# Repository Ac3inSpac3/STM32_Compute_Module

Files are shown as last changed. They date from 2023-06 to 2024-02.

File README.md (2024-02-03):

# Custom STM32 Compute Module

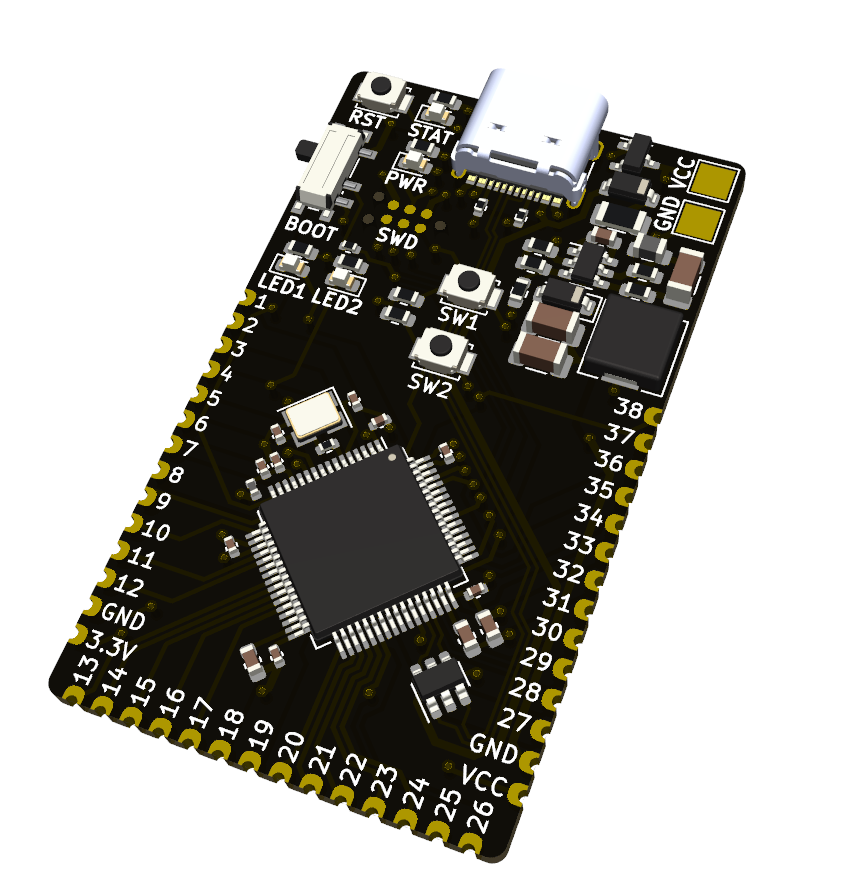
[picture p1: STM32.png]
Module Image


## Introduction

In order to wrap my head around using KiCAD I decided to design an STM32 compute module. The goal of this exercise was to familiarise myself with the program enough so that I was comfortable designing PCBs and getting them manufactured for Uni and personal projects. Due to the high cost of manufacturing this board and the possibility of it not working it was never manufactured/tested and was purely a way for me to learn how to use KiCAD.

## Features

- STM32F4 Microcontroller
- Full breakout of GPIO pins
- Voltage Regulator with fuse
- USBC
- SWD tag connector

## Module Overview

In theory this board is capable of being the heart of many different projects as a replacement for the slow Arduino boards.

## Images

### PCB

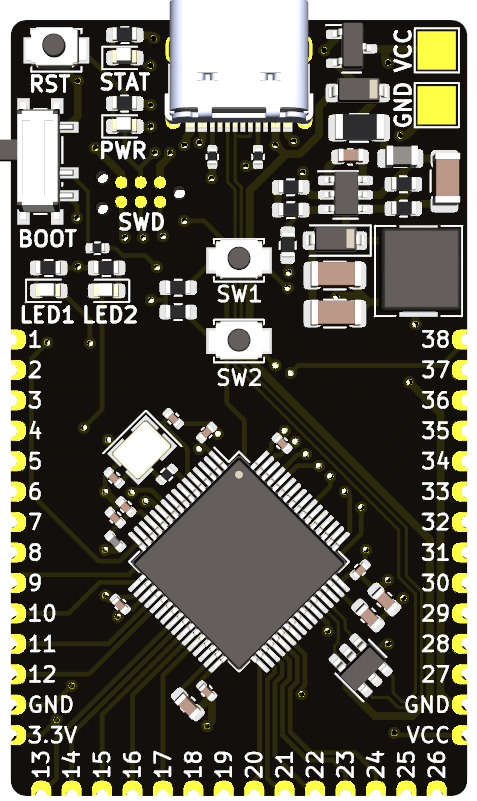
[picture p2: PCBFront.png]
Module Front


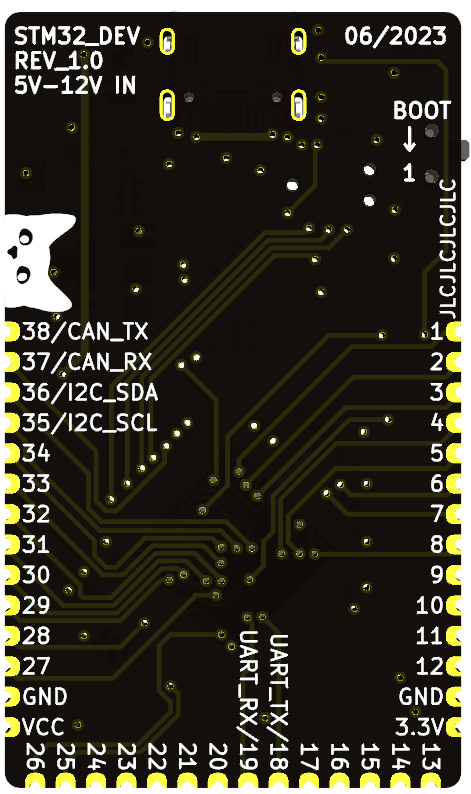
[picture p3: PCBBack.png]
Module Back


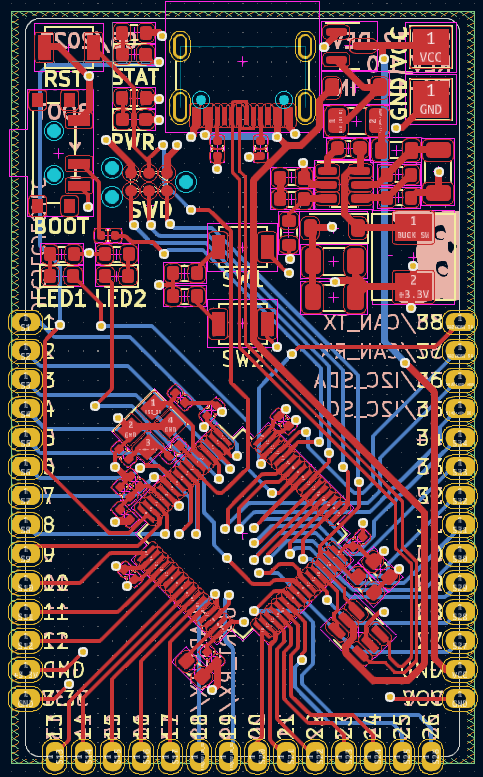
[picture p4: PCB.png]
PCB


### Schematic

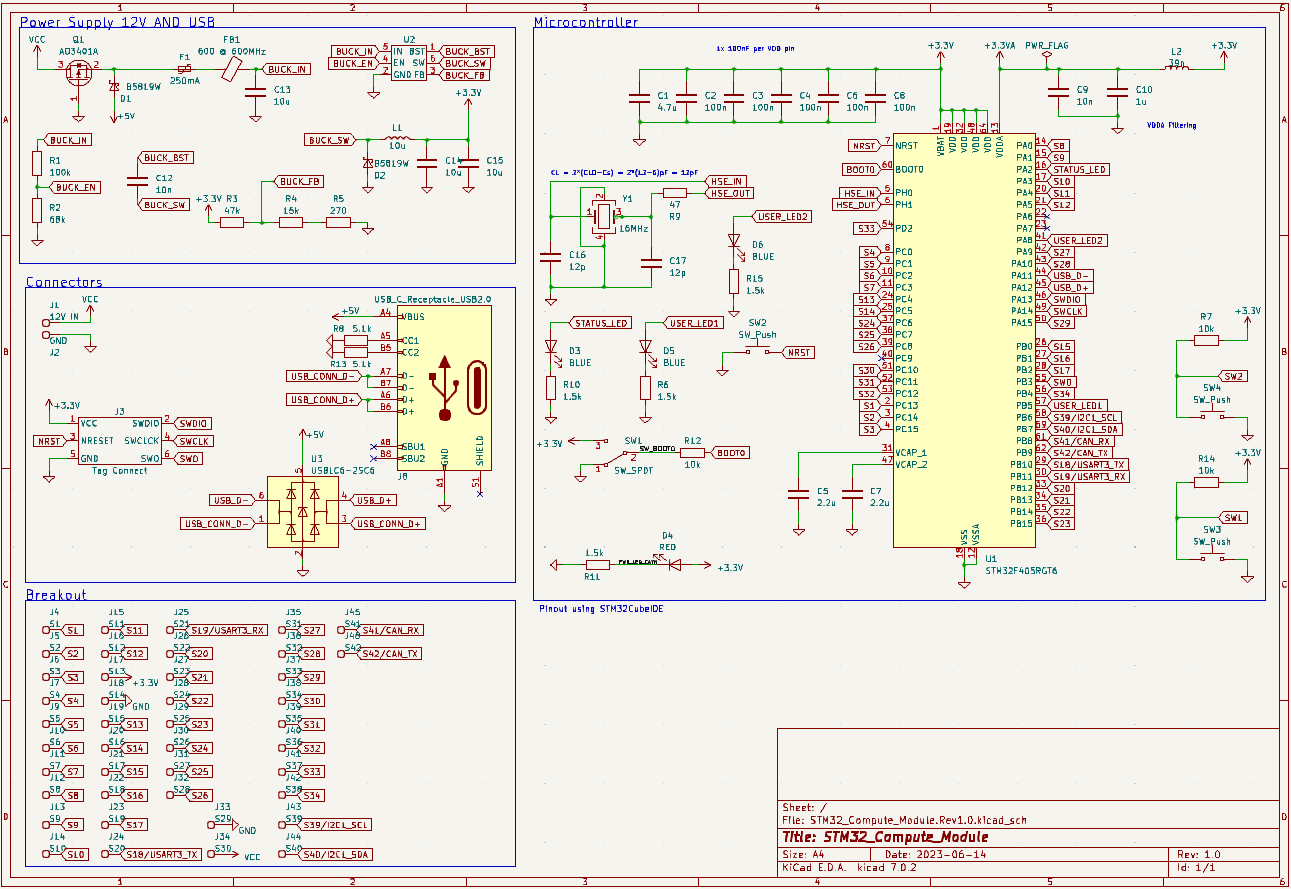
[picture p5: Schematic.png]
STM32 Schematic


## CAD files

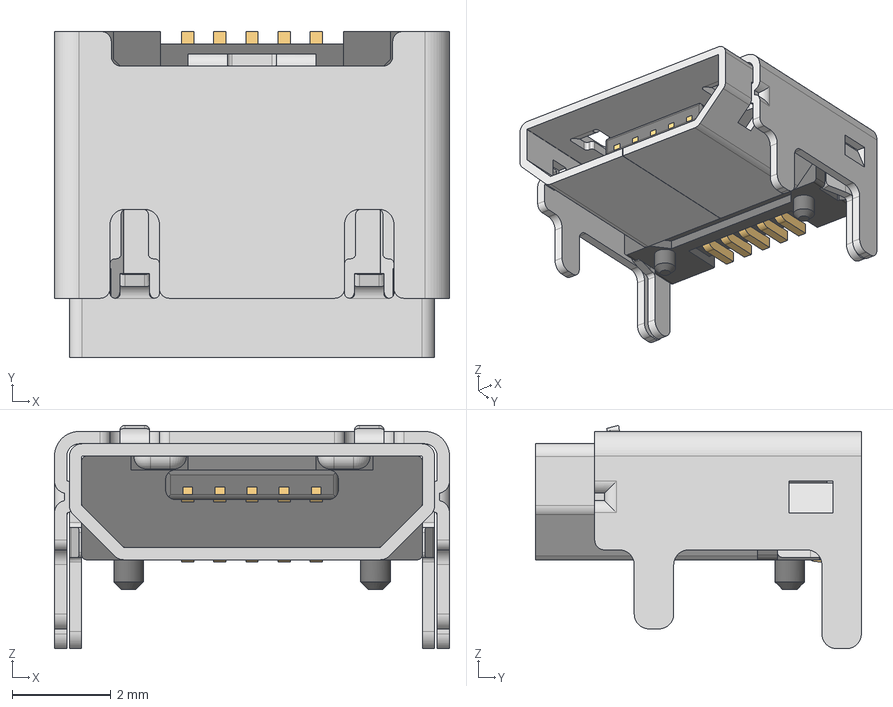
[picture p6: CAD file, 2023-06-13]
KiCAD/629105150521 (rev1).stp
8.00 x 6.60 x 4.52 mm
629105150521_Housing
629105150521_Pin1 x 4
629105150521_Pin2
629105150521_Shielding2
629105150521_Shielding

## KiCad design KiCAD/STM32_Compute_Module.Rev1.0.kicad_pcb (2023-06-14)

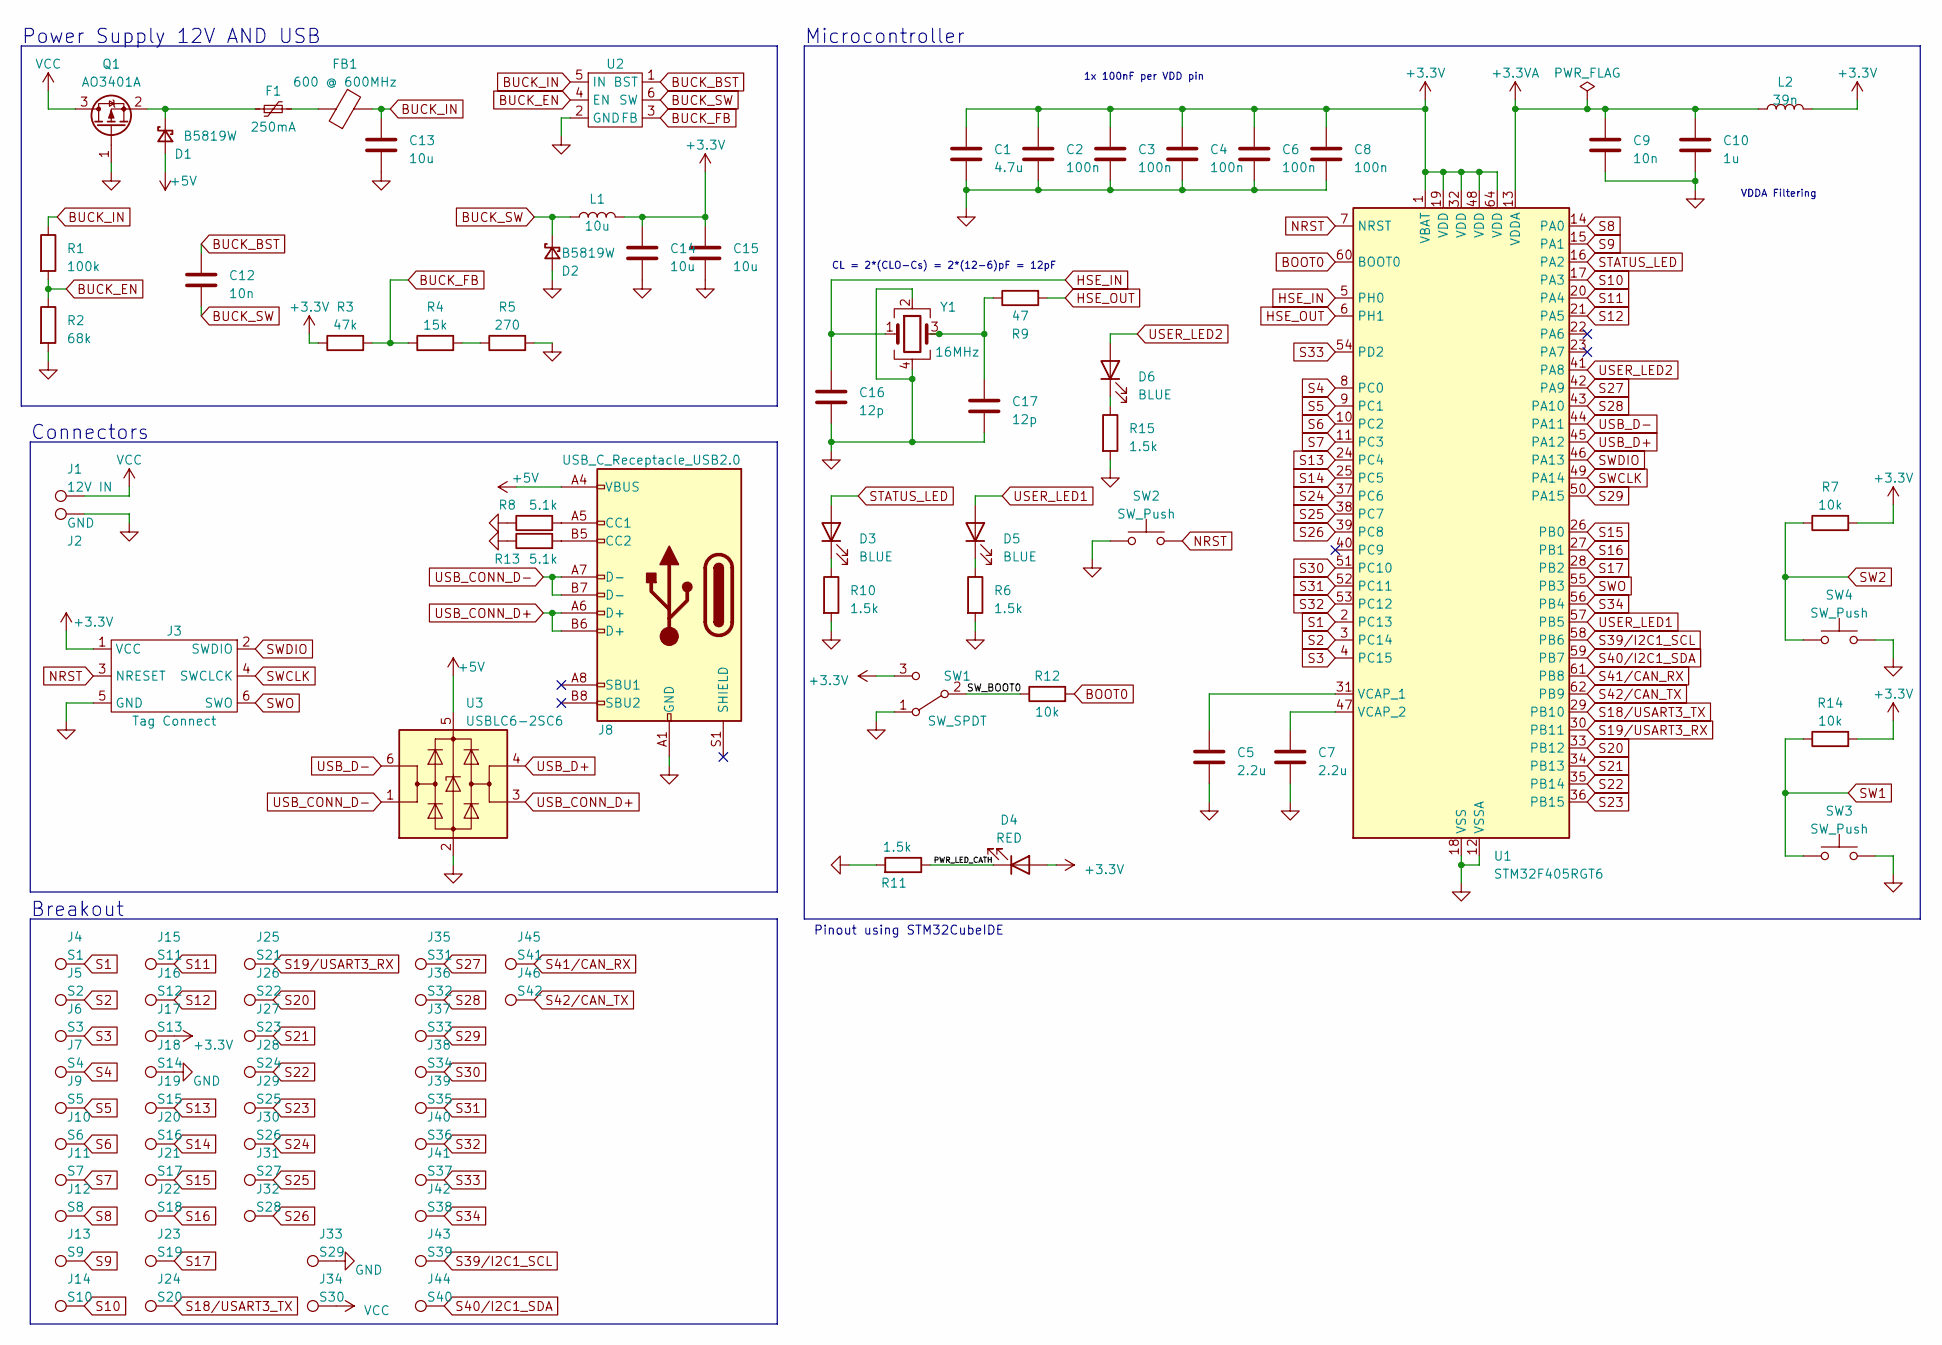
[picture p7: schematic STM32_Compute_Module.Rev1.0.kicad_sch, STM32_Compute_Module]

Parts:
C1: 4.7u; C_0603_1608Metric
C2, C3, C4, C6, C8: 100n; C_0402_1005Metric
C5, C7: 2.2u; C_0603_1608Metric
C9: 10n; C_0402_1005Metric
C10: 1u; C_0402_1005Metric
C12: 10n; C_0603_1608Metric
C13, C14, C15: 10u; C_1206_3216Metric
C16, C17: 12p; C_0402_1005Metric
D1, D2: B5819W; D_SOD-123
D3, D5, D6: BLUE; LED_0603_1608Metric
D4: RED; LED_0603_1608Metric
F1: 250mA; Fuse_1206_3216Metric
FB1: 600 @ 600MHz; L_0805_2012Metric
J1: 12V IN; TestPoint_Pad_2.5x2.5mm
J2: GND; TestPoint_Pad_2.5x2.5mm
J3: Tag Connect
J4: S1; Cas Pad
J5: S2; Cas Pad
J6: S3; Cas Pad
J7: S4; Cas Pad
J8: USB_C_Receptacle_USB2.0; USB_C_Receptacle_G-Switch_GT-USB-7010ASV
J9: S5; Cas Pad
J10: S6; Cas Pad
J11: S7; Cas Pad
J12: S8; Cas Pad
J13: S9; Cas Pad
J14: S10; Cas Pad
J15: S11; Cas Pad
J16: S12; Cas Pad
J17: S13; Cas Pad
J18: S14; Cas Pad
J19: S15; Cas Pad
J20: S16; Cas Pad
J21: S17; Cas Pad
J22: S18; Cas Pad
J23: S19; Cas Pad
J24: S20; Cas Pad
J25: S21; Cas Pad
J26: S22; Cas Pad
J27: S23; Cas Pad
J28: S24; Cas Pad
J29: S25; Cas Pad
J30: S26; Cas Pad
J31: S27; Cas Pad
J32: S28; Cas Pad
J33: S29; Cas Pad
J34: S30; Cas Pad
J35: S31; Cas Pad
J36: S32; Cas Pad
J37: S33; Cas Pad
J38: S34; Cas Pad
J39: S35; Cas Pad
J40: S36; Cas Pad
J41: S37; Cas Pad
J42: S38; Cas Pad
J43: S39; Cas Pad
J44: S40; Cas Pad
J45: S41; Cas Pad
J46: S42; Cas Pad
L1: 10u; L_Sunlord_MWSA0518S
L2: 39n; L_0402_1005Metric
Q1: AO3401A; SOT-23
R1: 100k; R_0603_1608Metric
R2: 68k; R_0603_1608Metric
R3: 47k; R_0603_1608Metric
R4: 15k; R_0603_1608Metric
R5: 270; R_0603_1608Metric
R6, R10, R11, R15: 1.5k; R_0603_1608Metric
R7, R14: 10k; R_0603_1608Metric
R8, R13: 5.1k; R_0402_1005Metric
R9: 47; R_0402_1005Metric
R12: 10k; R_0402_1005Metric
SW1: SW_SPDT; SW_SPDT_PCM12
SW2, SW3, SW4: SW_Push; SW_SPST_B3U-1000P
U1: STM32F405RGT6; LQFP-64_10x10mm_P0.5mm
U2: TSOT-23-6
U3: USBLC6-2SC6; SOT-23-6
Y1: 16MHz; Crystal_SMD_3225-4Pin_3.2x2.5mm

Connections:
+3.3V: C1.1, C2.1, C3.1, C4.1, C6.1, C8.1, C14.1, C15.1, D4.2 (A), J3.1 (VCC), J17.1, L1.2, L2.2, R3.1, R7.2, R14.2, SW1.3 (C), U1.1 (VBAT), U1.19 (VDD), U1.32 (VDD), U1.48 (VDD), U1.64 (VDD)
+3.3VA: C9.1, C10.1, L2.1, U1.13 (VDDA)
+5V: D1.2 (A), J8.A4 (VBUS), J8.A9 (VBUS), J8.B4 (VBUS), J8.B9 (VBUS), U3.5 (VBUS)
/PWR_LED_CATH: D4.1 (K), R11.1
/SW_BOOT0: R12.1, SW1.2 (B)
BOOT0: R12.2, U1.60 (BOOT0)
BUCK_BST: C12.1, U2.1 (BST)
BUCK_EN: R1.2, R2.1, U2.4 (EN)
BUCK_FB: R3.2, R4.1, U2.3 (FB)
BUCK_IN: C13.1, FB1.2, R1.1, U2.5 (IN)
BUCK_SW: C12.2, D2.1 (K), L1.1, U2.6 (SW)
GND: C1.2, C2.2, C3.2, C4.2, C5.2, C6.2, C7.2, C8.2, C9.2, C10.2, C13.2, C14.2, C15.2, C16.2, C17.2, D2.2 (A), J2.1, J3.5 (GND), J8.A1 (GND), J8.A12 (GND), J8.B1 (GND), J8.B12 (GND), J18.1, J33.1, Q1.1 (G), R2.2, R5.2, R6.2, R8.1, R10.2, R11.2, R13.1, R15.2, SW1.1 (A), SW2.1, SW3.1, SW4.1, U1.12 (VSSA), U1.18 (VSS), U1.63 (VSS), U2.2 (GND), U3.2 (GND), Y1.2, Y1.4
HSE_IN: C16.1, U1.5 (PH0), Y1.1
HSE_OUT: R9.2, U1.6 (PH1)
NRST: J3.3 (NRESET), SW2.2, U1.7 (NRST)
unnamed: C17.1, R9.1, Y1.3
unnamed: D1.1 (K), F1.1, Q1.2 (S)
unnamed: D3.1 (K), R10.1
unnamed: D5.1 (K), R6.1
unnamed: D6.1 (K), R15.1
unnamed: F1.2, FB1.1
unnamed: J8.A5 (CC1), R8.2
unnamed: J8.B5 (CC2), R13.2
unnamed: R4.2, R5.1
unnamed: C5.1, U1.31 (VCAP_1)
unnamed: C7.1, U1.47 (VCAP_2)
S1: J4.1, U1.2 (PC13)
S2: J5.1, U1.3 (PC14)
S3: J6.1, U1.4 (PC15)
S4: J7.1, U1.8 (PC0)
S5: J9.1, U1.9 (PC1)
S6: J10.1, U1.10 (PC2)
S7: J11.1, U1.11 (PC3)
S8: J12.1, U1.14 (PA0)
S9: J13.1, U1.15 (PA1)
S10: J14.1, U1.17 (PA3)
S11: J15.1, U1.20 (PA4)
S12: J16.1, U1.21 (PA5)
S13: J19.1, U1.24 (PC4)
S14: J20.1, U1.25 (PC5)
S15: J21.1, U1.26 (PB0)
S16: J22.1, U1.27 (PB1)
S17: J23.1, U1.28 (PB2)
S18/USART3_TX: J24.1, U1.29 (PB10)
S19/USART3_RX: J25.1, U1.30 (PB11)
S20: J26.1, U1.33 (PB12)
S21: J27.1, U1.34 (PB13)
S22: J28.1, U1.35 (PB14)
S23: J29.1, U1.36 (PB15)
S24: J30.1, U1.37 (PC6)
S25: J31.1, U1.38 (PC7)
S26: J32.1, U1.39 (PC8)
S27: J35.1, U1.42 (PA9)
S28: J36.1, U1.43 (PA10)
S29: J37.1, U1.50 (PA15)
S30: J38.1, U1.51 (PC10)
S31: J39.1, U1.52 (PC11)
S32: J40.1, U1.53 (PC12)
S33: J41.1, U1.54 (PD2)
S34: J42.1, U1.56 (PB4)
S39/I2C1_SCL: J43.1, U1.58 (PB6)
S40/I2C1_SDA: J44.1, U1.59 (PB7)
S41/CAN_RX: J45.1, U1.61 (PB8)
S42/CAN_TX: J46.1, U1.62 (PB9)
STATUS_LED: D3.2 (A), U1.16 (PA2)
SW1: R14.1, SW3.2
SW2: R7.1, SW4.2
SWCLK: J3.4 (SWCLCK), U1.49 (PA14)
SWDIO: J3.2 (SWDIO), U1.46 (PA13)
SWO: J3.6 (SWO), U1.55 (PB3)
USB_CONN_D+: J8.A6 (D+), J8.B6 (D+), U3.3 (I/O2)
USB_CONN_D-: J8.A7 (D-), J8.B7 (D-), U3.1 (I/O1)
USB_D+: U1.45 (PA12), U3.4 (I/O2)
USB_D-: U1.44 (PA11), U3.6 (I/O1)
USER_LED1: D5.2 (A), U1.57 (PB5)
USER_LED2: D6.2 (A), U1.41 (PA8)
VCC: J1.1, J34.1, Q1.3 (D)

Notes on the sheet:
1x 100nF per VDD pin
Power Supply 12V AND USB
CL = 2*(CLO-Cs) = 2*(12-6)pF = 12pF
Breakout
VDDA Filtering
Microcontroller
Connectors
Pinout using STM32CubeIDE

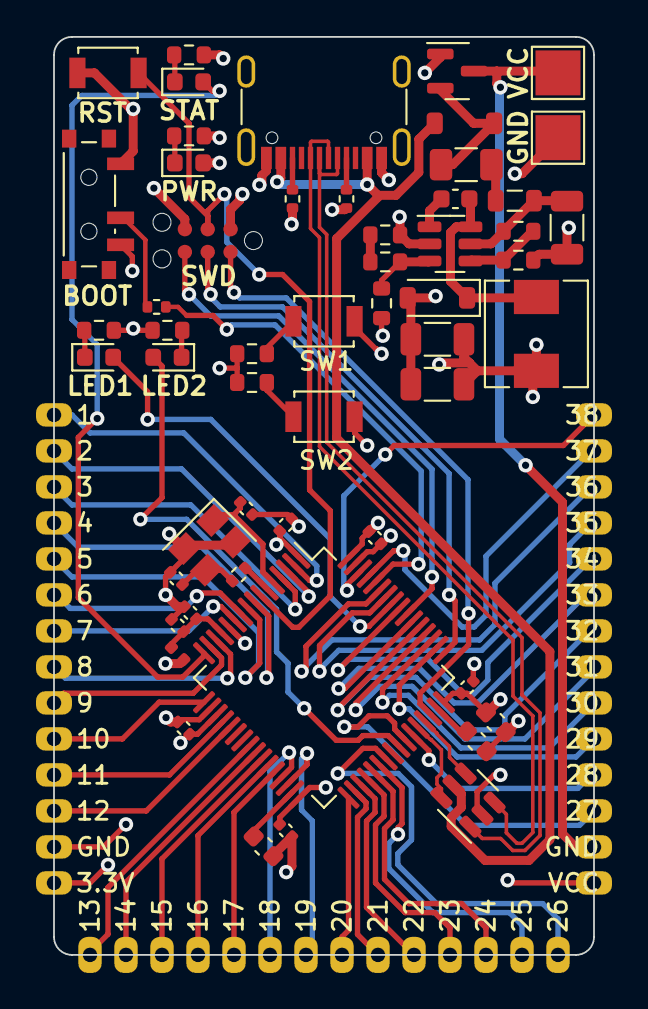
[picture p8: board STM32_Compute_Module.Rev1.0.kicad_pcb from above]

Board: 4 copper layers, 30.0 x 51.0 mm, 96 parts (0 on the bottom side), 77 nets.

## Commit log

2023-06-13 Added PCB KiCAD
    [629105150521 (rev1).stp, STM32_Simple_Rev1.0.kicad_pcb, STM32_Simple_Rev1.0.kicad_sch]
2023-06-14 Folder Name Update
    [629105150521 (rev1).stp, STM32_Simple_Rev1.0.kicad_pcb, STM32_Simple_Rev1.0.kicad_sch]
2023-06-14 Added manufacturing files and renamed
    [STM32_Compute_Module.Rev1.0.kicad_pcb, STM32_Compute_Module.Rev1.0.kicad_sch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]
2023-06-14 Added JLC PCB serial number location
    [STM32_Compute_Module.Rev1.0.kicad_pcb]
